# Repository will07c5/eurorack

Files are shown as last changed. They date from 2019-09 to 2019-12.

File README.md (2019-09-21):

This an attempt to build various basic analog synthesizer parts in the Eurorack form-factor. It is currently using clones of Curtis Electromusic ICs. Why, you might ask? Mostly just for fun and education.

The circuits are mostly based on the datasheets and various circuits around the web. In particular the triangle to sine conversion in the VCO uses part of Ray Wilson's VCO circuit.

Build at your own risk!

Note that these are currently only partially tested and working.

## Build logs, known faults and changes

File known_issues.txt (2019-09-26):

================ AS3340_VCO =================

================ AS3310_ADSR ================

================ AS3360_VCA =================

================ AS3320_VCF =================

================ ER_Bus_Board ===============

- "Upside down" (power input is on the left rather than the right)
- Missing descriptions of ports on the silk screen
- Need more metal around mounting holes

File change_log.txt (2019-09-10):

================ AS3340_VCO ================

Rev. 1:

- Initial design using SMD ICs.

Rev. 2:

- Added text indicating type of board and rev
- Switched to socketed DIP chips for easier repair
- Changed tuning method to 4 pot (as described in the AS3340 tuning doc)
- Adjusted various resistor values.
- Switched to precision input resistors

================ AS3320_VCF ================

Rev. 1:

- Initial design

================ AS3360_VCA ================

Rev. 1:

- Initial design

================ AS3310_ADSR ===============

Rev. 1:

- Initial design

================ ER_Bus_Board ==============

Rev. 1:

- Initial design

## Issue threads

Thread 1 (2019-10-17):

ADSR: LED incorrectly connected.

will07c5, 2019-10-17:
LED should be at minimum brightness when the envelope generator outputs 0V and max brightness at 5V output.

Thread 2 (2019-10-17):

ADSR: Resistors under AS3310

will07c5, 2019-10-17:
When the AS3310 got switched to the other side of the board the resistors didn't get moved so they overlap with the IC.

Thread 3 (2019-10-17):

VCF: Mounting hole misaligned

will07c5, 2019-10-17:
One of the mounting holes between the Main board and IO board is misaligned.

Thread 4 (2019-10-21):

VCO: PWM CV voltage summer circuit is wrong

will07c5, 2019-10-21:
There's a missing resistor between the first and second op amp.

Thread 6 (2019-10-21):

ADSR: Sustain resistor values are wrong

will07c5, 2019-10-21:
Sustain input differs from attack, decay and release. Needs to divide form 12V to 5V rather than 12V to 224mV.

Closed 2019-12-01.

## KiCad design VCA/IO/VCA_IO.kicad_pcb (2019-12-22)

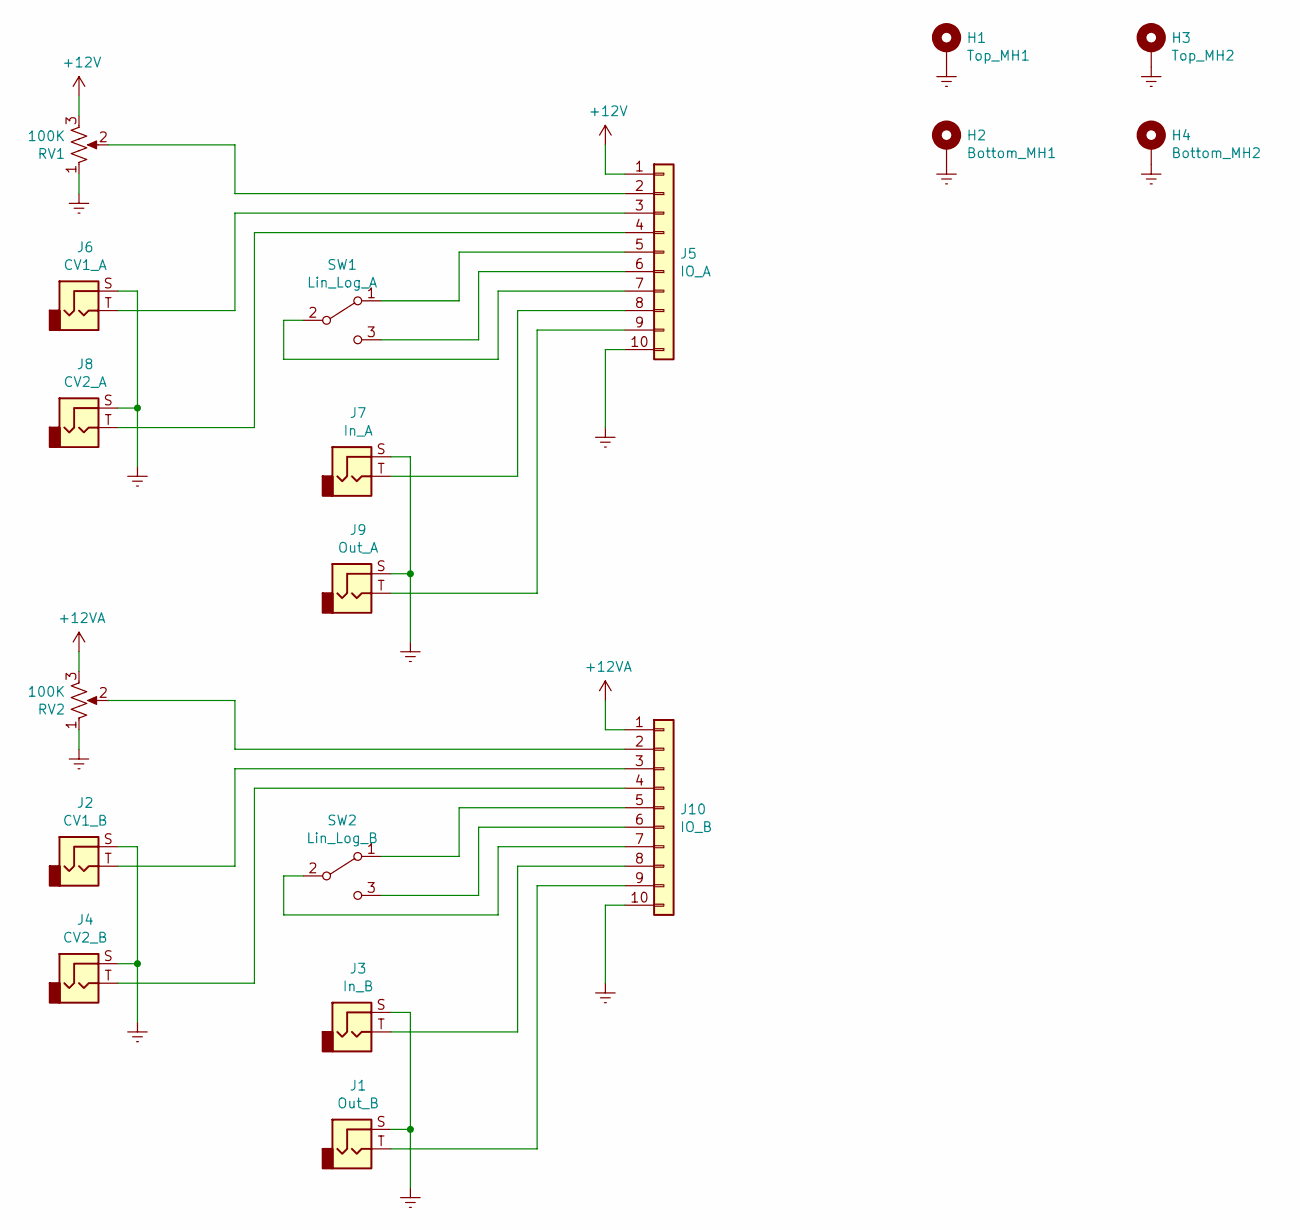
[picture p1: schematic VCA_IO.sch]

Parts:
H1: Top_MH1; eurorack_mounting_hole
H2: Bottom_MH1; eurorack_mounting_hole
H3: Top_MH2; eurorack_mounting_hole
H4: Bottom_MH2; eurorack_mounting_hole
J1: Out_B; Jack_3.5mm_QingPu_WQP-PJ398SM_Vertical_CircularHoles
J2: CV1_B; Jack_3.5mm_QingPu_WQP-PJ398SM_Vertical_CircularHoles
J3: In_B; Jack_3.5mm_QingPu_WQP-PJ398SM_Vertical_CircularHoles
J4: CV2_B; Jack_3.5mm_QingPu_WQP-PJ398SM_Vertical_CircularHoles
J5: IO_A; PinSocket_1x10_P2.54mm_Vertical
J6: CV1_A; Jack_3.5mm_QingPu_WQP-PJ398SM_Vertical_CircularHoles
J7: In_A; Jack_3.5mm_QingPu_WQP-PJ398SM_Vertical_CircularHoles
J8: CV2_A; Jack_3.5mm_QingPu_WQP-PJ398SM_Vertical_CircularHoles
J9: Out_A; Jack_3.5mm_QingPu_WQP-PJ398SM_Vertical_CircularHoles
J10: IO_B; PinSocket_1x10_P2.54mm_Vertical
RV1, RV2: 100K; Potentiometer_TT_P0915N
SW1: Lin_Log_A; switch
SW2: Lin_Log_B; switch

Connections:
+12V: J5.1, RV1.3
+12VA: J10.1, RV2.3
GNDREF: H1.1, H2.1, H3.1, H4.1, J1.S, J2.S, J3.S, J4.S, J5.10, J6.S, J7.S, J8.S, J9.S, J10.10, RV1.1, RV2.1
unnamed: J1.T, J10.9
unnamed: J5.2, RV1.2
unnamed: J5.3, J6.T
unnamed: J5.4, J8.T
unnamed: J5.5, SW1.1 (A)
unnamed: J5.6, SW1.3 (C)
unnamed: J5.7, SW1.2 (B)
unnamed: J5.8, J7.T
unnamed: J5.9, J9.T
unnamed: J10.2, RV2.2
unnamed: J2.T, J10.3
unnamed: J4.T, J10.4
unnamed: J10.5, SW2.1 (A)
unnamed: J10.6, SW2.3 (C)
unnamed: J10.7, SW2.2 (B)
unnamed: J3.T, J10.8

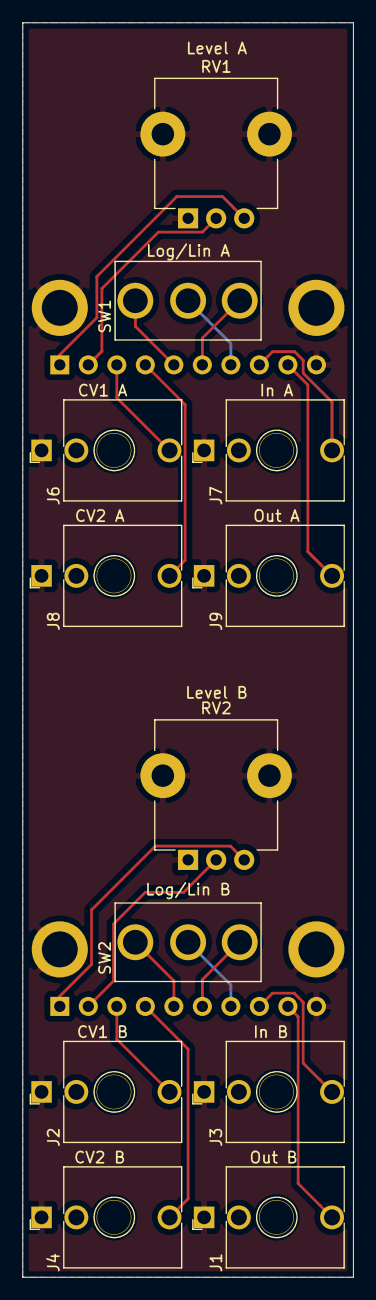
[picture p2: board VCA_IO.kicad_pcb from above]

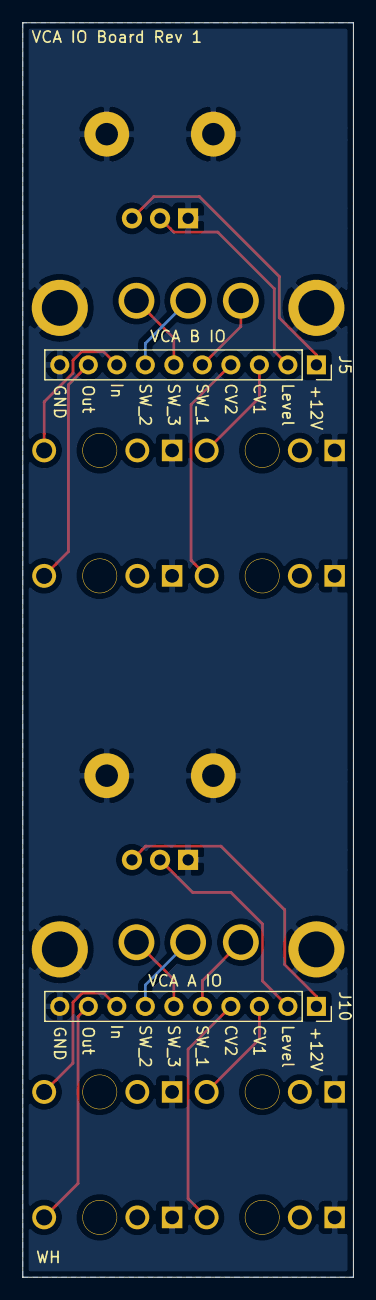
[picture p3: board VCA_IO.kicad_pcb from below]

Board: 2 copper layers, 29.5 x 111.8 mm, 18 parts (2 on the bottom side), 19 nets.

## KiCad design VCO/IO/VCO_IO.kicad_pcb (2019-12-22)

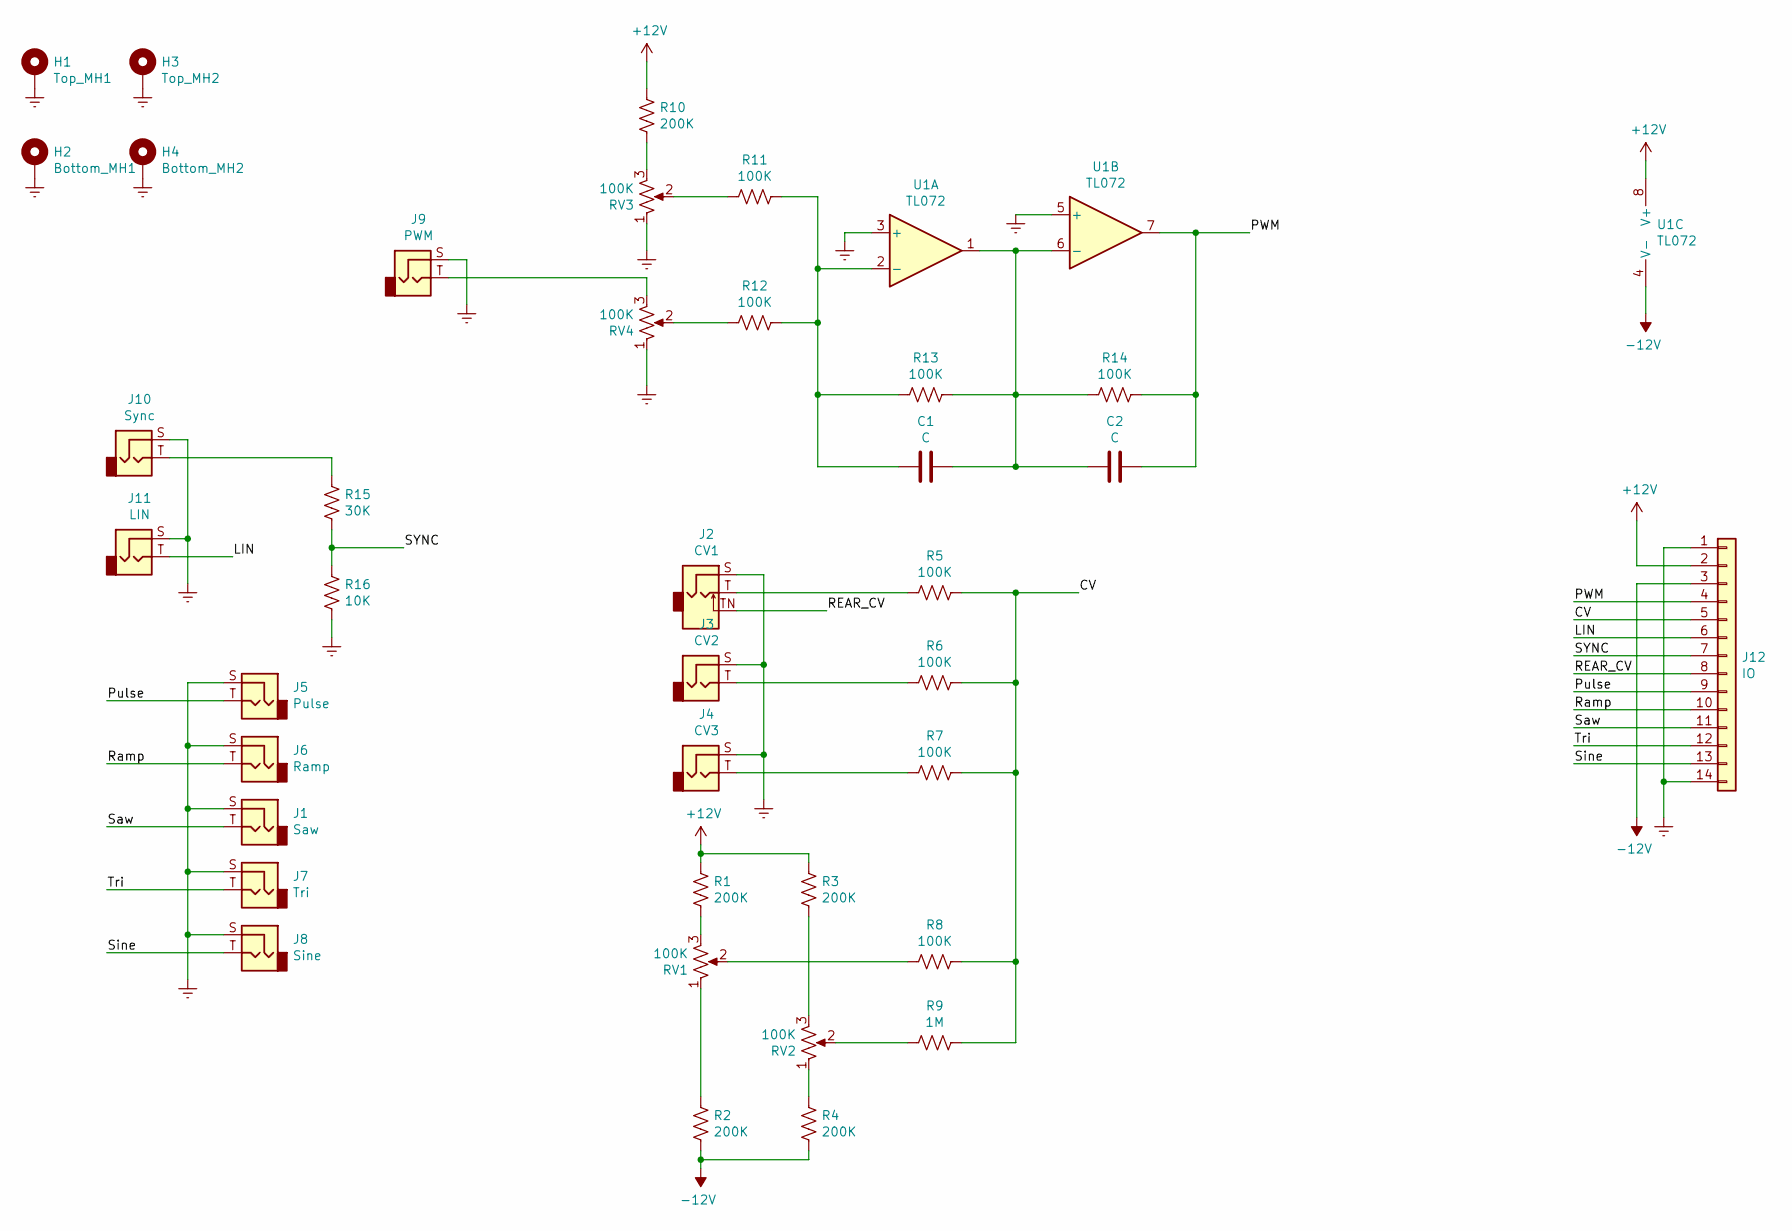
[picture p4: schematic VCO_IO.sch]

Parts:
C1, C2: C; C_0805_2012Metric
H1: Top_MH1; eurorack_mounting_hole
H2: Bottom_MH1; eurorack_mounting_hole
H3: Top_MH2; eurorack_mounting_hole
H4: Bottom_MH2; eurorack_mounting_hole
J1: Saw; Jack_3.5mm_QingPu_WQP-PJ398SM_Vertical_CircularHoles
J2: CV1; Jack_3.5mm_QingPu_WQP-PJ398SM_Vertical_CircularHoles
J3: CV2; Jack_3.5mm_QingPu_WQP-PJ398SM_Vertical_CircularHoles
J4: CV3; Jack_3.5mm_QingPu_WQP-PJ398SM_Vertical_CircularHoles
J5: Pulse; Jack_3.5mm_QingPu_WQP-PJ398SM_Vertical_CircularHoles
J6: Ramp; Jack_3.5mm_QingPu_WQP-PJ398SM_Vertical_CircularHoles
J7: Tri; Jack_3.5mm_QingPu_WQP-PJ398SM_Vertical_CircularHoles
J8: Sine; Jack_3.5mm_QingPu_WQP-PJ398SM_Vertical_CircularHoles
J9: PWM; Jack_3.5mm_QingPu_WQP-PJ398SM_Vertical_CircularHoles
J10: Sync; Jack_3.5mm_QingPu_WQP-PJ398SM_Vertical_CircularHoles
J11: LIN; Jack_3.5mm_QingPu_WQP-PJ398SM_Vertical_CircularHoles
J12: IO; PinSocket_1x14_P2.54mm_Vertical
R1, R2, R3, R4, R10: 200K; R_0805_2012Metric
R5, R6, R7, R8, R11, R12, R13, R14: 100K; R_0805_2012Metric
R9: 1M; R_0805_2012Metric
R15: 30K; R_0805_2012Metric
R16: 10K; R_0805_2012Metric
RV1, RV2, RV3, RV4: 100K; Potentiometer_TT_P0915N
U1: TL072; DIP-8_W7.62mm

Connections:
+12V: J12.2, R1.1, R3.1, R10.1, U1.8 (V+)
-12V: J12.3, R2.2, R4.2, U1.4 (V-)
/CV: J12.5, R5.1, R6.1, R7.1, R8.1, R9.1
/LIN: J11.T, J12.6
/PWM: C2.1, J12.4, R14.1, U1.7
/Pulse: J5.T, J12.9
/REAR_CV: J2.TN, J12.8
/Ramp: J6.T, J12.10
/SYNC: J12.7, R15.2, R16.1
/Saw: J1.T, J12.11
/Sine: J8.T, J12.13
/Tri: J7.T, J12.12
GNDREF: H1.1, H2.1, H3.1, H4.1, J1.S, J2.S, J3.S, J4.S, J5.S, J6.S, J7.S, J8.S, J9.S, J10.S, J11.S, J12.1, J12.14, R16.2, RV3.1, RV4.1, U1.3 (+), U1.5 (+)
unnamed: C1.1, C2.2, R13.1, R14.2, U1.1, U1.6 (-)
unnamed: C1.2, R11.1, R12.1, R13.2, U1.2 (-)
unnamed: J2.T, R5.2
unnamed: J3.T, R6.2
unnamed: J4.T, R7.2
unnamed: J9.T, RV4.3
unnamed: J10.T, R15.1
unnamed: R1.2, RV1.3
unnamed: R2.1, RV1.1
unnamed: R3.2, RV2.3
unnamed: R4.1, RV2.1
unnamed: R8.2, RV1.2
unnamed: R9.2, RV2.2
unnamed: R10.2, RV3.3
unnamed: R11.2, RV3.2
unnamed: R12.2, RV4.2

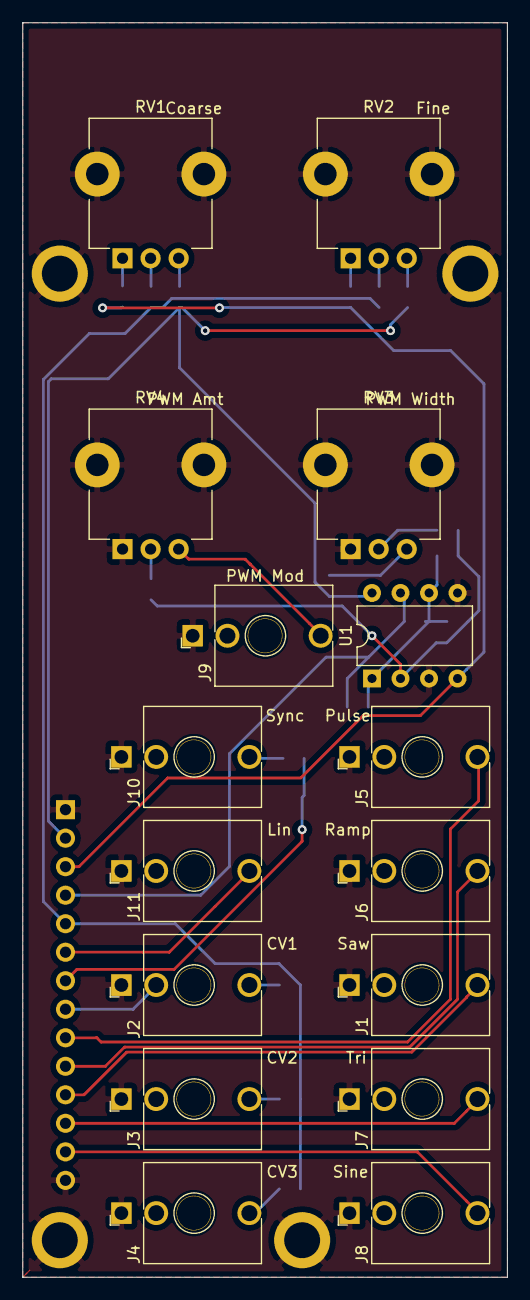
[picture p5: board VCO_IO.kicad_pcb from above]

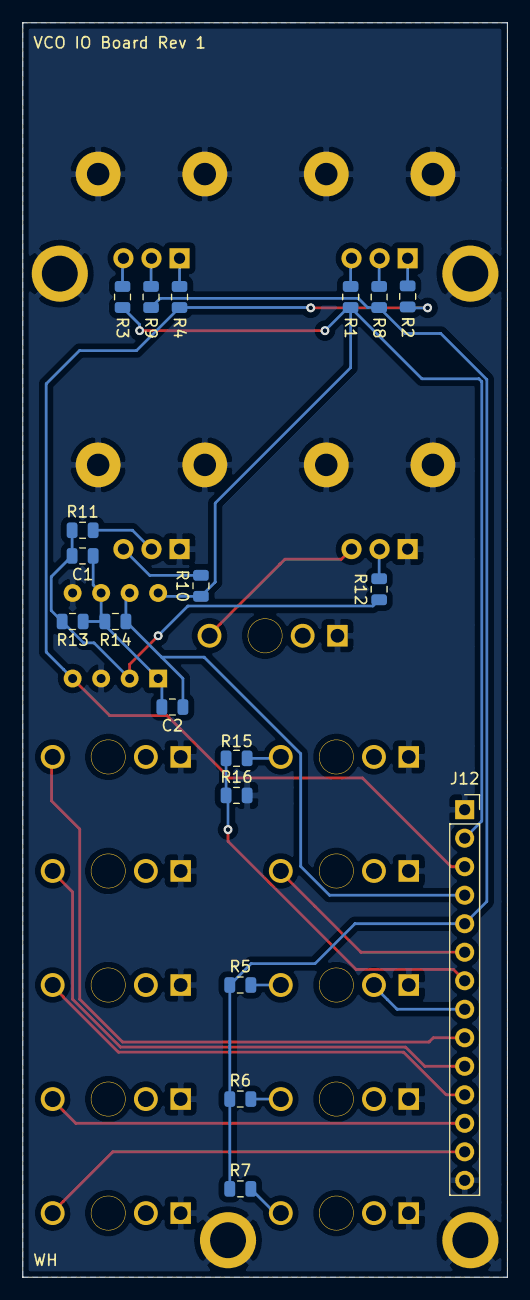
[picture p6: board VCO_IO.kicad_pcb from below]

Board: 2 copper layers, 43.2 x 111.8 mm, 39 parts (19 on the bottom side), 29 nets.

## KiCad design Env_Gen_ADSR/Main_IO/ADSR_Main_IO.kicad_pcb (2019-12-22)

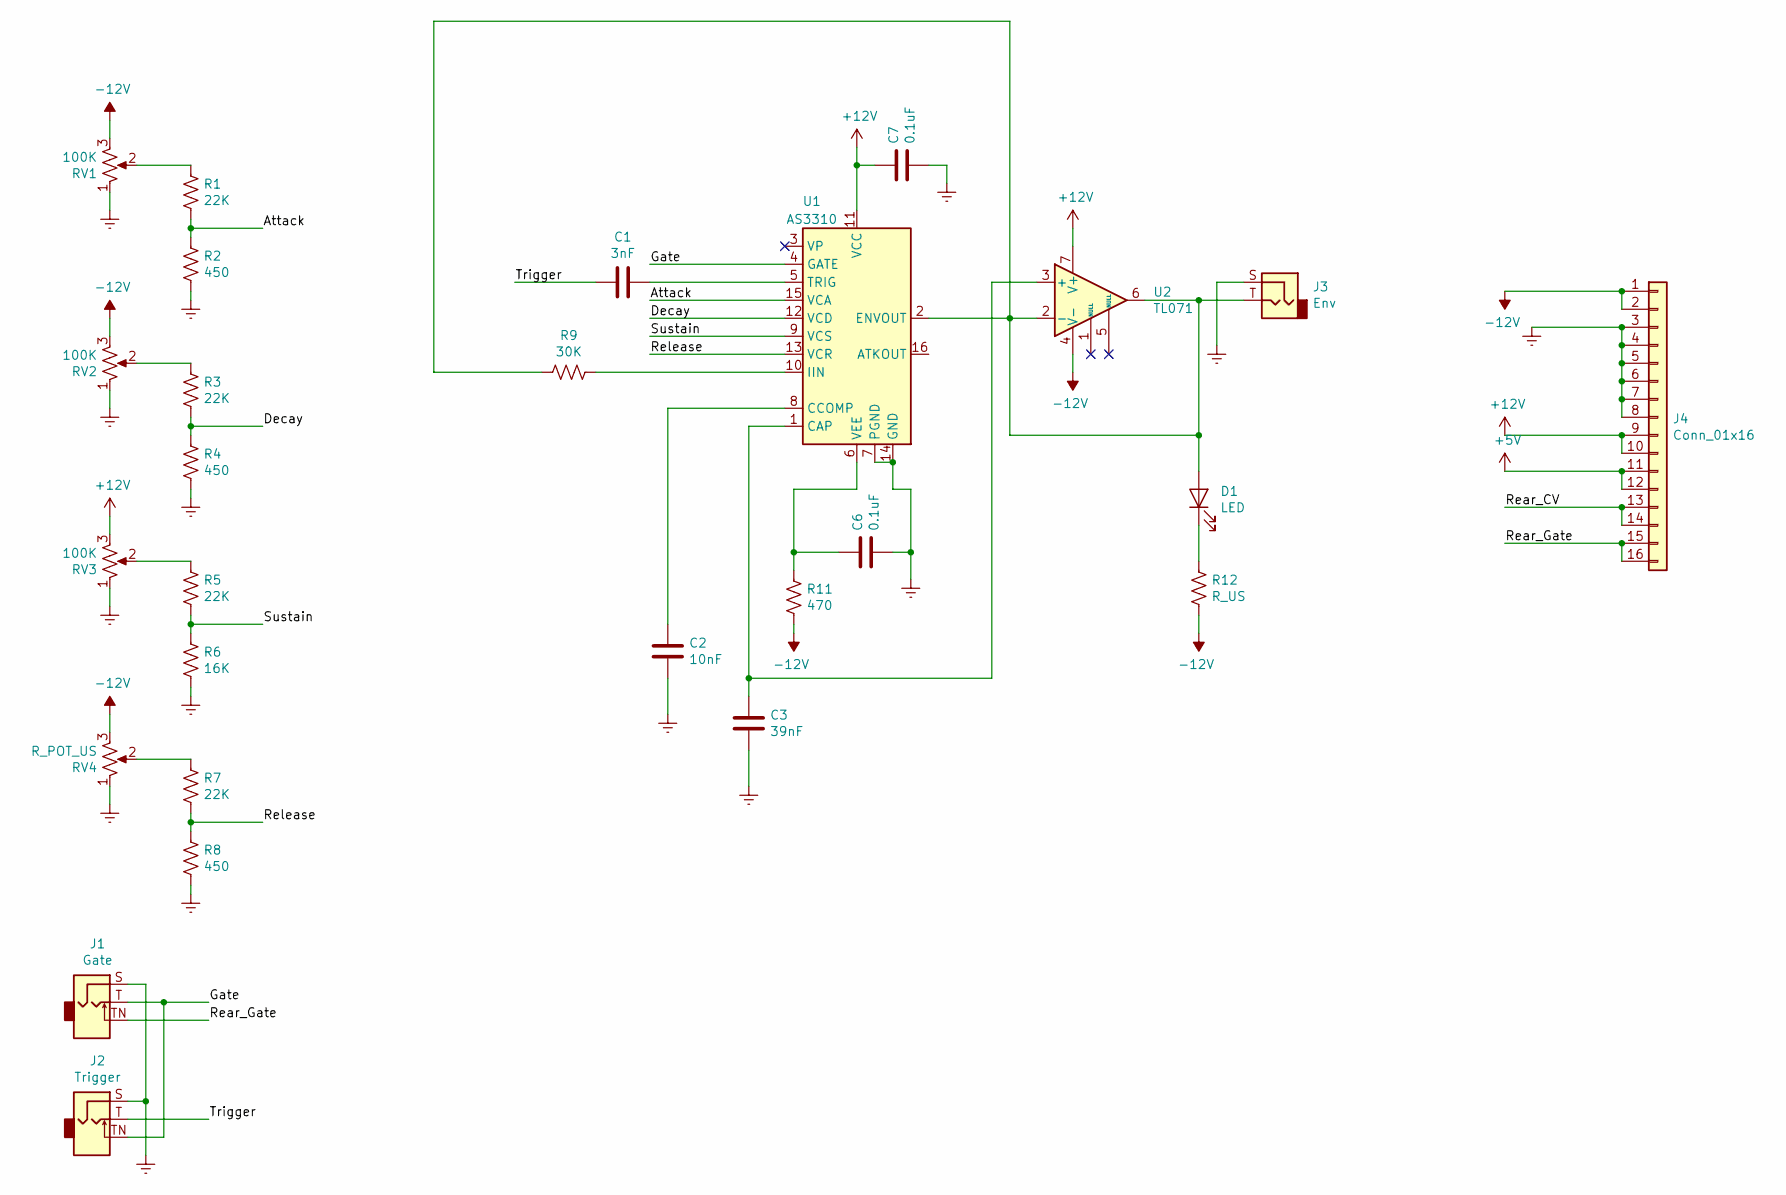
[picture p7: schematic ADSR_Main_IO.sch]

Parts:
C1: 3nF; C_0805_2012Metric
C2: 10nF; C_0805_2012Metric
C3: 39nF; C_0805_2012Metric
C6, C7: 0.1uF; C_0805_2012Metric
D1: LED; LED_D5.0mm
J1: Gate; Jack_3.5mm_QingPu_WQP-PJ398SM_Vertical_CircularHoles
J2: Trigger; Jack_3.5mm_QingPu_WQP-PJ398SM_Vertical_CircularHoles
J3: Env; Jack_3.5mm_QingPu_WQP-PJ398SM_Vertical_CircularHoles
J4: Conn_01x16; IDC-Header_2x08_P2.54mm_Vertical
R1, R3, R5, R7: 22K; R_0805_2012Metric
R2, R4, R8: 450; R_0805_2012Metric
R6: 16K; R_0805_2012Metric
R9: 30K; R_0805_2012Metric
R11: 470; R_0805_2012Metric
R12: R_US; R_0805_2012Metric
RV1, RV2, RV3: 100K; Potentiometer_TT_P0915N
RV4: R_POT_US; Potentiometer_TT_P0915N
U1: AS3310; DIP-16_W7.62mm
U2: TL071; DIP-8_W7.62mm

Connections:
+5V: J4.11, J4.12
+12V: C7.1, J4.9, J4.10, RV3.3, U1.11 (VCC), U2.7 (V+)
-12V: J4.1, J4.2, R11.2, R12.2, RV1.3, RV2.3, RV4.3, U2.4 (V-)
/Attack: R1.2, R2.1, U1.15 (VCA)
/Decay: R3.2, R4.1, U1.12 (VCD)
/Gate: J1.T, J2.TN, U1.4 (GATE)
/Rear_CV: J4.13, J4.14
/Rear_Gate: J1.TN, J4.15, J4.16
/Release: R7.2, R8.1, U1.13 (VCR)
/Sustain: R5.2, R6.1, U1.9 (VCS)
/Trigger: C1.2, J2.T
GNDREF: C2.2, C3.2, C6.2, C7.2, J1.S, J2.S, J3.S, J4.3, J4.4, J4.5, J4.6, J4.7, J4.8, R2.2, R4.2, R6.2, R8.2, RV1.1, RV2.1, RV3.1, RV4.1, U1.7 (PGND), U1.14 (GND)
unnamed: C1.1, U1.5 (TRIG)
unnamed: C2.1, U1.8 (CCOMP)
unnamed: C3.1, U1.1 (CAP), U2.3 (+)
unnamed: C6.1, R11.1, U1.6 (VEE)
unnamed: D1.1 (K), R12.1
unnamed: D1.2 (A), J3.T, R9.2, U1.2 (ENVOUT), U2.2 (-), U2.6
unnamed: R1.1, RV1.2
unnamed: R3.1, RV2.2
unnamed: R5.1, RV3.2
unnamed: R7.1, RV4.2
unnamed: R9.1, U1.10 (IIN)

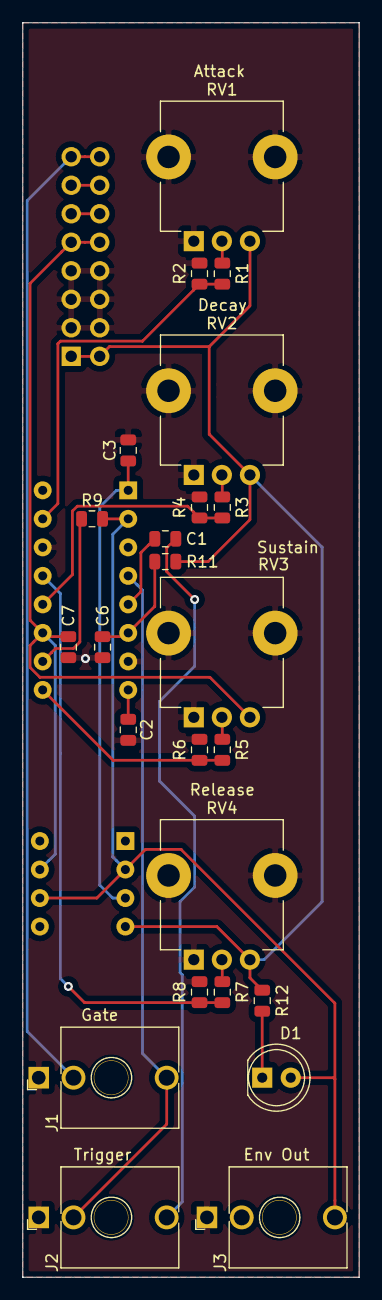
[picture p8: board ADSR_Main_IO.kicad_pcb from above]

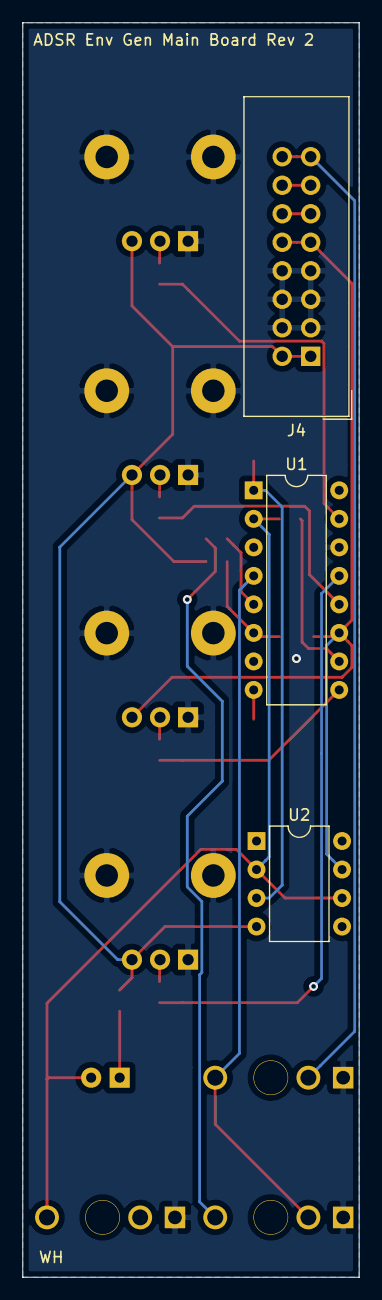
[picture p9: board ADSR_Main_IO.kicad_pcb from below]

Board: 2 copper layers, 30.0 x 111.8 mm, 27 parts (3 on the bottom side), 23 nets.

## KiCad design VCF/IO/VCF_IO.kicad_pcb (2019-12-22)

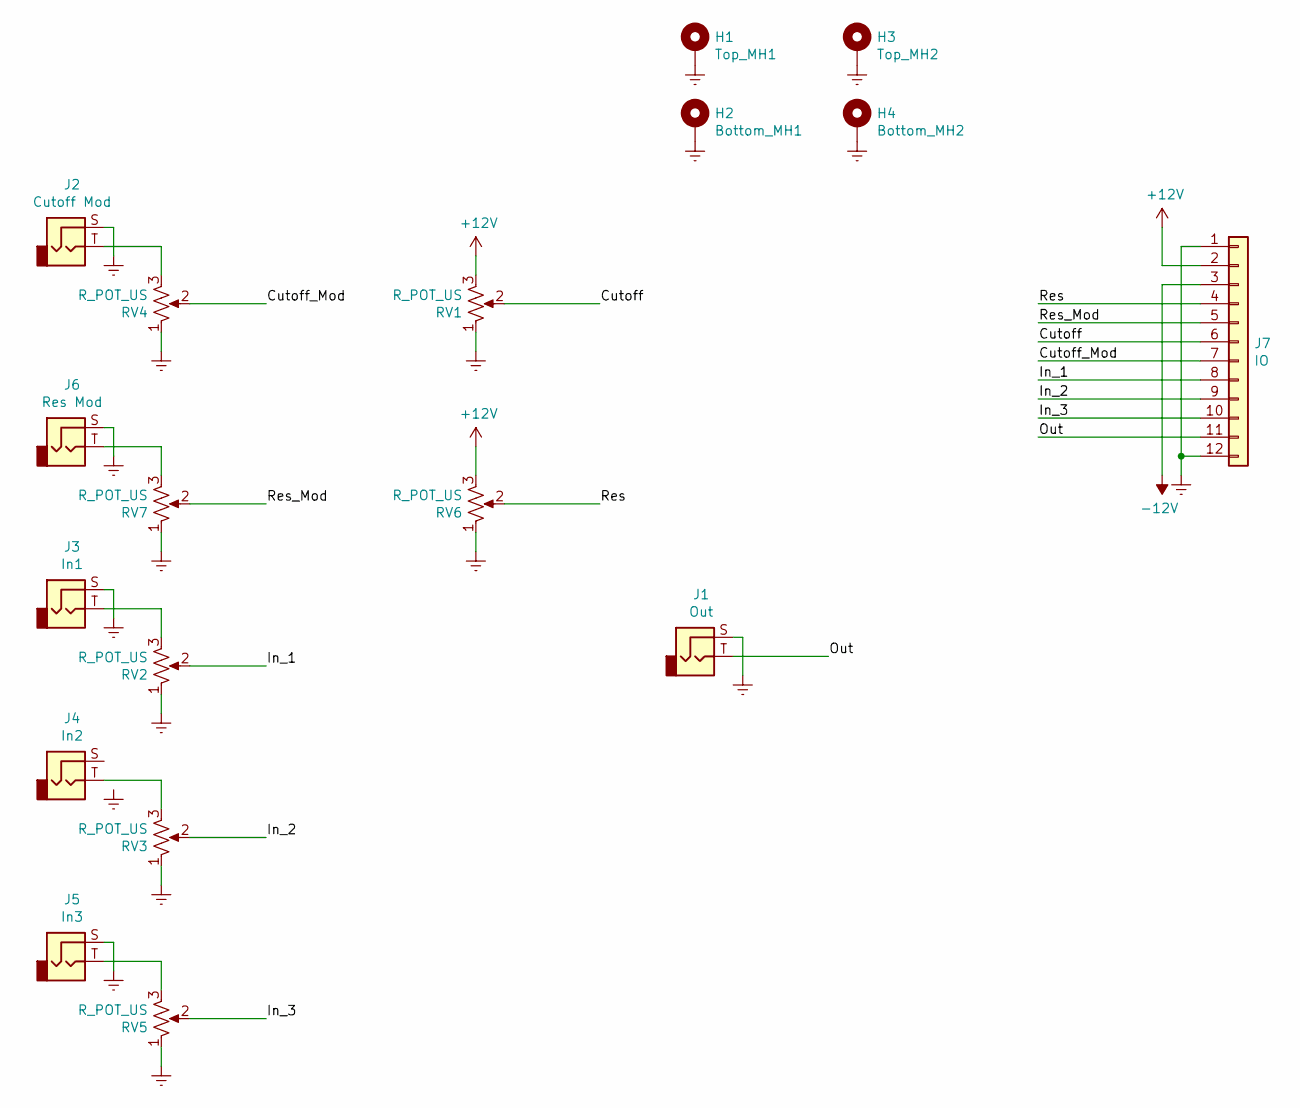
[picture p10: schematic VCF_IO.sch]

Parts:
H1: Top_MH1; eurorack_mounting_hole
H2: Bottom_MH1; eurorack_mounting_hole
H3: Top_MH2; eurorack_mounting_hole
H4: Bottom_MH2; eurorack_mounting_hole
J1: Out; Jack_3.5mm_QingPu_WQP-PJ398SM_Vertical_CircularHoles
J2: Cutoff Mod; Jack_3.5mm_QingPu_WQP-PJ398SM_Vertical_CircularHoles
J3: In1; Jack_3.5mm_QingPu_WQP-PJ398SM_Vertical_CircularHoles
J4: In2; Jack_3.5mm_QingPu_WQP-PJ398SM_Vertical_CircularHoles
J5: In3; Jack_3.5mm_QingPu_WQP-PJ398SM_Vertical_CircularHoles
J6: Res Mod; Jack_3.5mm_QingPu_WQP-PJ398SM_Vertical_CircularHoles
J7: IO; PinSocket_1x12_P2.54mm_Vertical
RV1, RV2, RV3, RV4, RV5, RV6, RV7: R_POT_US; Potentiometer_TT_P0915N

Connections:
+12V: J7.2, RV1.3, RV6.3
-12V: J7.3
/Cutoff: J7.6, RV1.2
/Cutoff_Mod: J7.7, RV4.2
/In_1: J7.8, RV2.2
/In_2: J7.9, RV3.2
/In_3: J7.10, RV5.2
/Out: J1.T, J7.11
/Res: J7.4, RV6.2
/Res_Mod: J7.5, RV7.2
GNDREF: H1.1, H2.1, H3.1, H4.1, J1.S, J2.S, J3.S, J5.S, J6.S, J7.1, J7.12, RV1.1, RV2.1, RV3.1, RV4.1, RV5.1, RV6.1, RV7.1
unnamed: J2.T, RV4.3
unnamed: J3.T, RV2.3
unnamed: J4.T, RV3.3
unnamed: J5.T, RV5.3
unnamed: J6.T, RV7.3

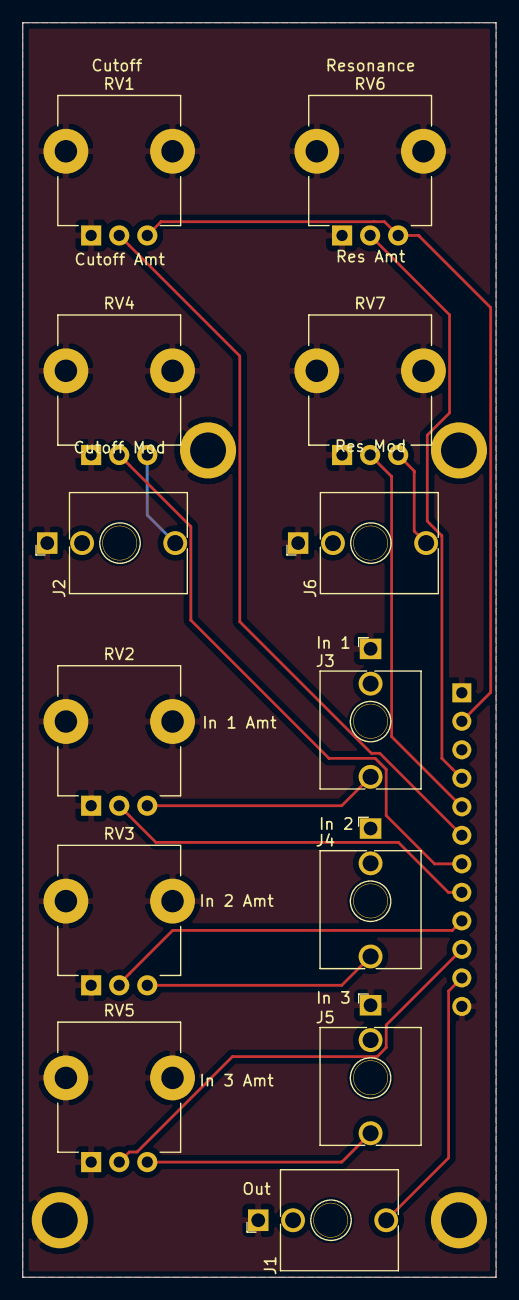
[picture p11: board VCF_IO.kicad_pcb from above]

Board: 2 copper layers, 42.2 x 111.8 mm, 18 parts (1 on the bottom side), 15 nets.

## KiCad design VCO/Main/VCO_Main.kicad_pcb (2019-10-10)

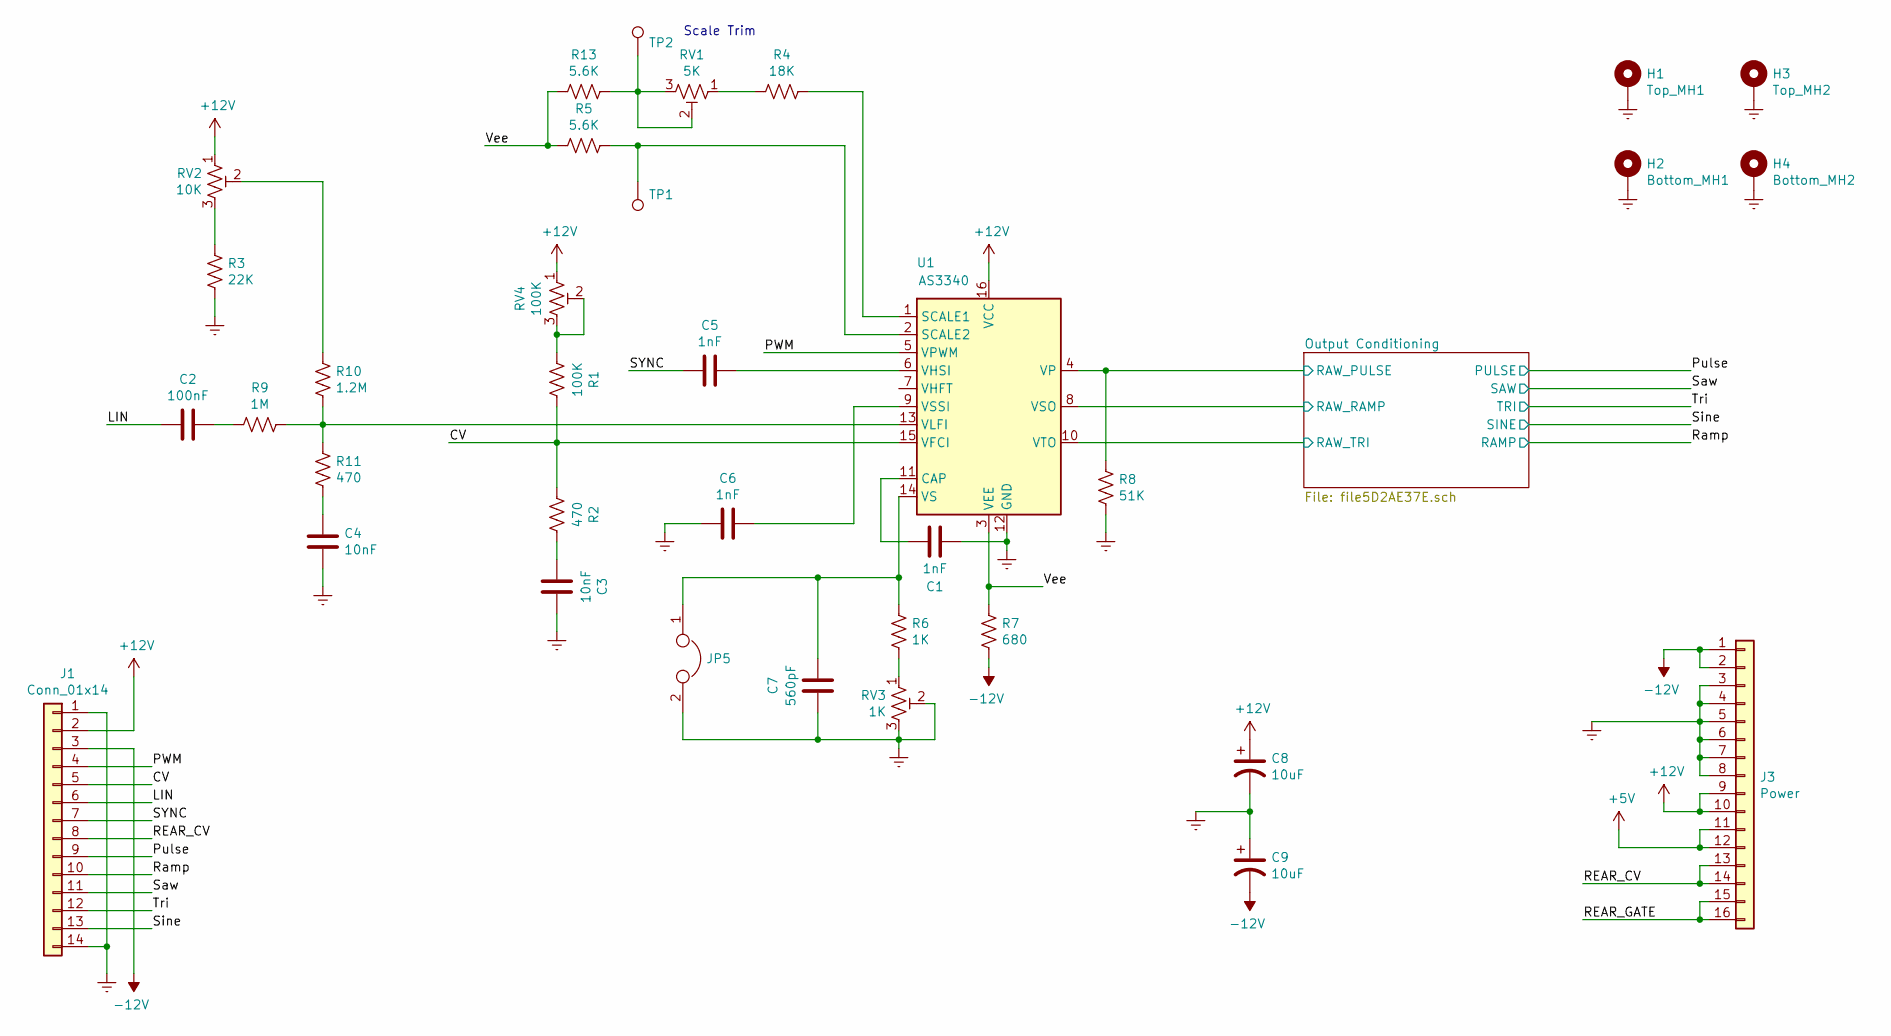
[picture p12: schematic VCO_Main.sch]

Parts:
C1: 1nF; Mica_Cap
C2: 100nF; C_0805_2012Metric
C3, C4: 10nF; C_0805_2012Metric
C5, C6: 1nF; C_0805_2012Metric
C7: 560pF; C_0805_2012Metric
C8, C9: 10uF; CP_Elec_4x3
H1: Top_MH1; eurorack_mounting_hole
H2: Bottom_MH1; eurorack_mounting_hole
H3: Top_MH2; eurorack_mounting_hole
H4: Bottom_MH2; eurorack_mounting_hole
J1: Conn_01x14; PinHeader_1x14_P2.54mm_Vertical
J3: Power; IDC-Header_2x08_P2.54mm_Vertical
JP5: Jumper; PinHeader_1x02_P2.54mm_Vertical
R1: 100K; R_0805_2012Metric
R2, R11: 470; R_0805_2012Metric
R3: 22K; R_0805_2012Metric
R4: 18K; R_0805_2012Metric
R5, R13: 5.6K; R_0805_2012Metric
R6: 1K; R_0805_2012Metric
R7: 680; R_0805_2012Metric
R8: 51K; R_0805_2012Metric
R9: 1M; R_0805_2012Metric
R10: 1.2M; R_0805_2012Metric
RV1: 5K; Potentiometer_Bourns_3296W_Vertical
RV2: 10K; Potentiometer_Bourns_3296W_Vertical
RV3: 1K; Potentiometer_Bourns_3296W_Vertical
RV4: 100K; Potentiometer_Bourns_3296W_Vertical
TP1, TP2: TestPoint; TestPoint_Pad_D2.0mm
U1: AS3340; DIP-16_W7.62mm

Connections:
+5V: J3.11, J3.12
+12V: C8.1, J1.2, J3.9, J3.10, RV2.1, RV4.1, U1.16 (VCC); also elsewhere on the board
-12V: C9.2, J1.3, J3.1, J3.2, R7.2; also elsewhere on the board
/CV: J1.5, R1.1, R2.2, U1.15 (VFCI)
/LIN: C2.2, J1.6
/Output Conditioning/RAW_PULSE: R8.2, U1.4 (VP); also elsewhere on the board
/Output Conditioning/RAW_RAMP: U1.8 (VSO); also elsewhere on the board
/Output Conditioning/RAW_TRI: U1.10 (VTO); also elsewhere on the board
/PWM: J1.4, U1.5 (VPWM)
/Pulse: J1.9; also elsewhere on the board
/REAR_CV: J1.8, J3.13, J3.14
/REAR_GATE: J3.15, J3.16
/Ramp: J1.10; also elsewhere on the board
/SYNC: C5.2, J1.7
/Saw: J1.11; also elsewhere on the board
/Sine: J1.13; also elsewhere on the board
/Tri: J1.12; also elsewhere on the board
/Vee: R5.1, R7.1, R13.1, U1.3 (VEE)
GNDREF: C1.1, C3.1, C4.1, C6.2, C7.1, C8.2, C9.1, H1.1, H2.1, H3.1, H4.1, J1.1, J1.14, J3.3, J3.4, J3.5, J3.6, J3.7, J3.8, JP5.2, R3.1, R8.1, RV3.2, RV3.3, U1.12 (GND); also elsewhere on the board
unnamed: C1.2, U1.11 (CAP)
unnamed: C2.1, R9.2
unnamed: C3.2, R2.1
unnamed: C4.2, R11.1
unnamed: C5.1, U1.6 (VHSI)
unnamed: C6.1, U1.9 (VSSI)
unnamed: C7.2, JP5.1, R6.2, U1.14 (VS)
unnamed: R1.2, RV4.2, RV4.3
unnamed: R3.2, RV2.3
unnamed: R4.1, RV1.1
unnamed: R4.2, U1.1 (SCALE1)
unnamed: R5.2, TP1.1, U1.2 (SCALE2)
unnamed: R6.1, RV3.1
unnamed: R9.1, R10.1, R11.2, U1.13 (VLFI)
unnamed: R10.2, RV2.2
unnamed: R13.2, RV1.2, RV1.3, TP2.1

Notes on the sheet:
Scale Trim


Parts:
C10, C11, C12, C13: C; C_0805_2012Metric
C14, C15, C16, C17, C18, C19: 0.1uF; C_0805_2012Metric
R12, R14, R24, R35, R36, R39: 10K; R_0805_2012Metric
R23, R29, R34, R37: 100K; R_0805_2012Metric
R25, R27: 20K; R_0805_2012Metric
R26: 470K; R_0805_2012Metric
R28, R33: 1K; R_0805_2012Metric
R30: 130K; R_0805_2012Metric
R31: 1M; R_0805_2012Metric
R32: 4.7K; R_0805_2012Metric
R38: 12K; R_0805_2012Metric
RV6, RV10, RV11: 20K; Potentiometer_Bourns_3296W_Vertical
RV7, RV8: 100K; Potentiometer_Bourns_3296W_Vertical
RV9: 1M; Potentiometer_Bourns_3296W_Vertical
U5: LM13700; DIP-16_W7.62mm
U6, U7: TL072; DIP-8_W7.62mm

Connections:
+12V: C14.2, C16.2, C18.2, R23.1, R31.1, R34.1, R37.1, RV8.1, RV9.3, U5.11 (V+), U6.8 (V+), U7.8 (V+); also elsewhere on the board
-12V: C15.2, C17.2, C19.2, R32.2, RV8.3, U5.6 (V-), U6.4 (V-), U7.4 (V-); also elsewhere on the board
/Output Conditioning/RAW_PULSE: R38.1; also elsewhere on the board
/Output Conditioning/RAW_RAMP: R35.1; also elsewhere on the board
/Output Conditioning/RAW_TRI: R24.1; also elsewhere on the board
/Pulse: C13.1, R39.2, U7.1; also elsewhere on the board
/Ramp: C12.1, R14.2, U6.7; also elsewhere on the board
/Saw: C10.1, R12.1, R36.2, U6.1; also elsewhere on the board
/Sine: R33.2; also elsewhere on the board
/Tri: C11.1, R25.2, RV7.1, U7.7; also elsewhere on the board
GNDREF: C14.1, C15.1, C16.1, C17.1, C18.1, C19.1, R28.2, R30.2, RV6.3, RV10.3, RV11.3, U5.3 (+), U5.13 (-), U5.14 (+), U6.5 (+); also elsewhere on the board
unnamed: C10.2, R35.2, R36.1, U6.2 (-)
unnamed: C11.2, R24.2, R25.1, U7.6 (-)
unnamed: C12.2, R12.2, R14.1, U6.6 (-)
unnamed: C13.2, R38.2, R39.1, U7.2 (-)
unnamed: R23.2, RV6.1
unnamed: R26.1, RV8.2
unnamed: R26.2, R27.1, R28.1, U5.4 (-)
unnamed: R27.2, RV7.2, RV7.3
unnamed: R29.1, U5.1
unnamed: R29.2, RV9.1, RV9.2
unnamed: R30.1, R31.2, U5.5, U5.7
unnamed: R32.1, R33.1, U5.8
unnamed: R34.2, RV10.1
unnamed: R37.2, RV11.1
unnamed: RV6.2, U7.5 (+)
unnamed: RV10.2, U6.3 (+)
unnamed: RV11.2, U7.3 (+)

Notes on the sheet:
Tri Offset Trim
Sine Bias Trim
Sine Shape Trim
Sine Level Trim
Saw Offset Trim
Pulse Offset Trim

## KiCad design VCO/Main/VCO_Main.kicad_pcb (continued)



Board: 2 copper layers, 43.2 x 92.7 mm, 73 parts (19 on the bottom side), 52 nets.

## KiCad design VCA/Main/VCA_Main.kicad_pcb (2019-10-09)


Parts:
C1, C2: CP1; CP_Elec_4x3
C3: 5nF; C_0805_2012Metric
C4, C5, C10, C11, C12, C13, C14, C15: 0.1uF; C_0805_2012Metric
C6, C7, C8, C9: C; C_0805_2012Metric
H1: Top_MH1; eurorack_mounting_hole
H2: Bottom_MH1; eurorack_mounting_hole
H3: Top_MH2; eurorack_mounting_hole
H4: Bottom_MH2; eurorack_mounting_hole
J1: Power; IDC-Header_2x05_P2.54mm_Vertical
J5: IO_A; PinHeader_1x10_P2.54mm_Vertical
J10: IO_B; PinHeader_1x10_P2.54mm_Vertical
R1, R2, R3, R4, R5, R6, R8, R9, R10, R11, R12, R13, R15: 100K; R_0805_2012Metric
R7: 240K; R_0805_2012Metric
R14, R16: 18K; R_0805_2012Metric
R17, R20: 16K; R_0805_2012Metric
R18, R19: 2.4K; R_0805_2012Metric
R21, R22, R23, R24: 47K; R_0805_2012Metric
U1: AS3360; DIP-14_W7.62mm
U2, U3, U4: TL072; DIP-8_W7.62mm

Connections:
+12V: C1.1, C4.2, C10.2, C12.2, C15.2, J1.9, J1.10, J5.1, J10.1, U1.14 (VCC), U2.8 (V+), U3.8 (V+), U4.8 (V+)
-12V: C2.2, C5.2, C11.2, C13.2, C14.2, J1.1, J1.2, U1.7 (VEE), U2.4 (V-), U3.4 (V-), U4.4 (V-)
/CV1_A: J5.3, R2.2
/CV1_B: J10.3, R5.2
/CV2_A: J5.4, R3.2
/CV2_B: J10.4, R6.2
/In_A: J5.8, R21.1
/In_B: J10.8, R22.1
/Level_A: J5.2, R1.2
/Level_B: J10.2, R4.2
/Out_A: J5.9, U4.6 (-), U4.7
/Out_B: J10.9, U4.1, U4.2 (-)
/SW_Com_A: J5.7, U1.12 (VE2)
/SW_Com_B: J10.7, U1.3 (VE1)
/SW_Lin_A: J5.5, U1.11 (VO2)
/SW_Lin_B: J10.5, U1.4 (VO1)
/SW_Log_A: J5.6, R17.2, R18.1
/SW_Log_B: J10.6, R19.2, R20.1
GNDREF: C1.2, C2.1, C3.2, C4.1, C5.1, C10.1, C11.1, C12.1, C13.1, C14.1, C15.1, H1.1, H2.1, H3.1, H4.1, J1.3, J1.4, J1.5, J1.6, J1.7, J1.8, J5.10, J10.10, R14.2, R16.2, R23.2, R24.2, U1.1 (GND), U2.3 (+), U2.5 (+), U3.3 (+), U3.5 (+)
unnamed: C3.1, R18.2, R19.1, U1.8 (VREF)
unnamed: C6.1, R7.1, R9.2, U2.1
unnamed: C6.2, R1.1, R2.1, R3.1, R7.2, U2.2 (-)
unnamed: C7.1, R8.1, R10.2, U3.1
unnamed: C7.2, R4.1, R5.1, R6.1, R8.2, U3.2 (-)
unnamed: C8.1, R11.1, R13.1, U2.7
unnamed: C8.2, R9.1, R11.2, U2.6 (-)
unnamed: C9.1, R12.1, R15.1, U3.7
unnamed: C9.2, R10.1, R12.2, U3.6 (-)
unnamed: R13.2, R14.1, R17.1, U1.10 (VC2)
unnamed: R15.2, R16.1, R20.2, U1.5 (VC1)
unnamed: R21.2, U1.9 (II2)
unnamed: R22.2, U1.6 (II1)
unnamed: R23.1, U1.13 (IO2), U4.5 (+)
unnamed: R24.1, U1.2 (IO1), U4.3 (+)



Board: 2 copper layers, 29.5 x 68.3 mm, 50 parts (5 on the bottom side), 34 nets.

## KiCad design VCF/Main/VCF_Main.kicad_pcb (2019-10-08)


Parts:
C1: 15uF; CP_Elec_4x3
C2, C3, C4, C5: 300pF; Mica_Cap
C6: 1uF; CP_Elec_4x3
C7: 33pF; C_0805_2012Metric
C8, C9: 10uF; CP_Elec_4x3
C10, C11, C12, C13: C; C_0805_2012Metric
C14, C15, C16, C17, C18, C19, C20, C21: 0.1uF; C_0805_2012Metric
H1: Top_MH1; eurorack_mounting_hole
H2: Bottom_MH1; eurorack_mounting_hole
H3: Top_MH2; eurorack_mounting_hole
H4: Bottom_MH2; eurorack_mounting_hole
J1: Power; PinHeader_1x12_P2.54mm_Vertical
J2: Power; IDC-Header_2x05_P2.54mm_Vertical
R1, R2, R3, R4, R12, R18, R21, R27, R31, R32: 100K; R_0805_2012Metric
R5, R6, R7, R9, R10, R14, R19, R22: 82K; R_0805_2012Metric
R8, R13, R20: 220K; R_0805_2012Metric
R11: 300K; R_0805_2012Metric
R15: 125K; R_0805_2012Metric
R16: 150K; R_0805_2012Metric
R17, R29: 200K; R_0805_2012Metric
R23: 44.2K; R_0805_2012Metric
R24: 39K; R_0805_2012Metric
R25: 47K; R_0805_2012Metric
R26: TC; Tempco
R28: 750; R_0805_2012Metric
R30: 1K; R_0805_2012Metric
RV6: 25K; Potentiometer_Bourns_3296W_Vertical
RV7: 1K; Potentiometer_Bourns_3296W_Vertical
U1, U2, U4: TL072; DIP-8_W7.62mm
U3: AS3320; DIP-18_W7.62mm

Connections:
+12V: C8.1, C15.2, C16.2, C18.2, C20.2, J1.2, J2.9, J2.10, U1.8 (V+), U2.8 (V+), U3.14 (VCC), U4.8 (V+)
-12V: C9.2, C17.2, C19.2, C21.2, J1.3, J2.1, J2.2, R8.1, R13.1, R16.2, R20.1, RV7.3, U1.4 (V-), U2.4 (V-), U4.4 (V-)
/Cutoff: J1.6, R15.2
/Cutoff_Mod: J1.7, R17.2
/In_1: J1.8, R1.2
/In_2: J1.9, R2.2
/In_3: J1.10, R3.2
/Out: J1.11, R30.1
/Res: J1.4, R11.2
/Res_Mod: J1.5, R12.2
GNDREF: C2.2, C3.2, C4.2, C5.2, C8.2, C9.1, C14.1, C15.1, C16.1, C17.1, C18.1, C19.1, C20.1, C21.1, H1.1, H2.1, H3.1, H4.1, J1.1, J1.12, J2.3, J2.4, J2.5, J2.6, J2.7, J2.8, R26.2, U1.3 (+), U1.5 (+), U2.3 (+), U2.5 (+), U3.3 (GND), U4.3 (+), U4.5 (+)
unnamed: C1.1, R5.2
unnamed: C1.2, C10.2, R4.1, U1.7
unnamed: C2.1, U3.5
unnamed: C3.1, U3.4
unnamed: C4.1, U3.16
unnamed: C5.1, U3.11
unnamed: C6.1, R22.1, U3.10
unnamed: C6.2, R25.2, R27.2
unnamed: C7.1, R27.1, R29.2, U1.2 (-)
unnamed: C7.2, R29.1, R30.2, U1.1
unnamed: C10.1, R1.1, R2.1, R3.1, R4.2, U1.6 (-)
unnamed: C11.1, R11.1, R12.1, R18.2, U2.2 (-)
unnamed: C11.2, R18.1, R32.2, U2.1
unnamed: C12.1, R15.1, R16.1, R17.1, R21.2, U4.6 (-)
unnamed: C12.2, R21.1, R23.2, U4.7
unnamed: C13.1, R31.2, R32.1, U2.6 (-)
unnamed: C13.2, R24.2, R31.1, U2.7
unnamed: C14.2, R28.1, U3.13 (VEE)
unnamed: R5.1, R6.2, U3.1
unnamed: R6.1, R7.2, U3.7
unnamed: R7.1, R8.2, R9.2, U3.2
unnamed: R10.1, R13.2, R14.2, U3.17
unnamed: R9.1, R10.2, U3.6
unnamed: R14.1, R19.2, U3.15
unnamed: R19.1, R20.2, R22.2, U3.18
unnamed: R23.1, RV6.2, RV6.3
unnamed: R24.1, U3.9 (IRES)
unnamed: R25.1, U3.8 (VRES)
unnamed: R26.1, RV6.1, U3.12 (VCFI)
unnamed: R28.2, RV7.1, RV7.2
unnamed: U4.1, U4.2 (-)



Board: 2 copper layers, 39.6 x 75.2 mm, 65 parts (14 on the bottom side), 42 nets.

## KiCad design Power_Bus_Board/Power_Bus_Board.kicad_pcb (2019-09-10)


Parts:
D1, D2, D3: LED; LED_D5.0mm
J1: Bus_8; IDC-Header_2x08_P2.54mm_Vertical
J2: Power_Out; TerminalBlock_bornier-4_P5.08mm
J3: CV_Gate_Out_2; PinHeader_1x03_P2.54mm_Vertical
J4: Bus_7; IDC-Header_2x08_P2.54mm_Vertical
J5: Bus_6; IDC-Header_2x08_P2.54mm_Vertical
J6: Bus_5; IDC-Header_2x08_P2.54mm_Vertical
J7: Bus_4; IDC-Header_2x08_P2.54mm_Vertical
J8: Bus_3; IDC-Header_2x08_P2.54mm_Vertical
J9: Bus_2; IDC-Header_2x08_P2.54mm_Vertical
J10: Bus_1; IDC-Header_2x08_P2.54mm_Vertical
J11: Power_In; TerminalBlock_bornier-4_P5.08mm
J12: CV_Gate_Out_1; TerminalBlock_bornier-3_P5.08mm
J13: CV_Gate_In_2; PinHeader_1x03_P2.54mm_Vertical
J14: CV_Gate_In_1; TerminalBlock_bornier-3_P5.08mm
R1, R2, R3: R_US; R_0805_2012Metric

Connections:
+5V: J1.11, J1.12, J2.1, J4.11, J4.12, J5.11, J5.12, J6.11, J6.12, J7.11, J7.12, J8.11, J8.12, J9.11, J9.12, J10.11, J10.12, J11.4, R3.1
+12V: J1.9, J1.10, J2.2, J4.9, J4.10, J5.9, J5.10, J6.9, J6.10, J7.9, J7.10, J8.9, J8.10, J9.9, J9.10, J10.9, J10.10, J11.3, R1.1
-12V: D2.1 (K), J1.1, J1.2, J2.4, J4.1, J4.2, J5.1, J5.2, J6.1, J6.2, J7.1, J7.2, J8.1, J8.2, J9.1, J9.2, J10.1, J10.2, J11.1
/CV: J1.13, J1.14, J3.2, J4.13, J4.14, J5.13, J5.14, J6.13, J6.14, J7.13, J7.14, J8.13, J8.14, J9.13, J9.14, J10.13, J10.14, J12.2, J13.2, J14.2
/Gate: J1.15, J1.16, J3.3, J4.15, J4.16, J5.15, J5.16, J6.15, J6.16, J7.15, J7.16, J8.15, J8.16, J9.15, J9.16, J10.15, J10.16, J12.3, J13.3, J14.3
GNDREF: D1.1 (K), D3.1 (K), J1.3, J1.4, J1.5, J1.6, J1.7, J1.8, J2.3, J3.1, J4.3, J4.4, J4.5, J4.6, J4.7, J4.8, J5.3, J5.4, J5.5, J5.6, J5.7, J5.8, J6.3, J6.4, J6.5, J6.6, J6.7, J6.8, J7.3, J7.4, J7.5, J7.6, J7.7, J7.8, J8.3, J8.4, J8.5, J8.6, J8.7, J8.8, J9.3, J9.4, J9.5, J9.6, J9.7, J9.8, J10.3, J10.4, J10.5, J10.6, J10.7, J10.8, J11.2, J12.1, J13.1, J14.1, R2.1
unnamed: D1.2 (A), R1.2
unnamed: D2.2 (A), R2.2
unnamed: D3.2 (A), R3.2


Board: 2 copper layers, 189.2 x 33.0 mm, 20 parts (0 on the bottom side), 9 nets.

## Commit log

2019-09-10 AS3340_VCO rev1 (with SMD ICs)
    [AS3340_VCO-B_Cu.gbr, AS3340_VCO-B_Mask.gbr, AS3340_VCO-B_Paste.gbr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]
2019-09-10 AS3340_VCO rev 2 AS3310_ADSR rev 1 AS3320_VCF rev 1 AS3360_VCA rev 1 ER_Bus_Board rev 1
    [AS3310_ADSR-B_Cu.gbr, AS3310_ADSR-B_Mask.gbr, AS3310_ADSR-B_Paste.gbr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]
2019-09-13 Add front panel and IO boards for VCO
    [AS3340_VCO_FP.kicad_pcb, AS3340_VCO_FP.sch, AS3340_VCO_IO.kicad_pcb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]
2019-09-13 Re-do VCO board to support new front panel board
    [AS3340_VCO.kicad_pcb, AS3340_VCO.sch, file5D2AE37E.sch]
2019-09-14 Adding front panel for ADSR
    [AS3310_ADSR_FP.kicad_pcb, AS3340_VCO_FP.sch]
2019-09-14 Combine IO and main ADSR boards
    [AS3310_ADSR-B_Cu.gbr, AS3310_ADSR-B_Mask.gbr, AS3310_ADSR-B_Paste.gbr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]
2019-09-20 Adding front panel board for VCA
    [AS3360_VCA_FP.kicad_pcb, AS3360_VCA_FP.sch]
2019-09-20 Organize boards in a more sane way.
    [ADSR_Front_Panel.kicad_pcb, ADSR_Front_Panel.sch, ADSR_Main_IO.kicad_pcb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]
2019-09-21 Add VCA IO board
    [VCA_Front_Panel.sch, VCA_IO.kicad_pcb, VCA_IO.sch]
2019-09-21 Update front panel to match IO board
    [VCA_Front_Panel.kicad_pcb]
2019-09-21 Re-doing VCA board to be compatible with new front panel design.
    [VCA_Main.kicad_pcb, VCA_Main.sch]
2019-09-24 Adding front panel board for VCF
    [VCF_Front_Panel.kicad_pcb, VCF_Front_Panel.sch]
2019-09-25 Move footprints to common folder and update known issues
2019-09-25 Add IO board for VCF
    [VCF_IO.kicad_pcb, VCF_IO.sch]
2019-09-25 Update VCF main board for new front panel
    [AS3320_VCF.kicad_pcb, VCF_Main.kicad_pcb, VCF_Main.sch]
2019-09-25 Add mounting holes for main board
    [VCF_IO.kicad_pcb]
2019-09-25 Fix envelope generator front panel size and alignment with IO board.
    [ADSR_Front_Panel.kicad_pcb, ADSR_Main_IO.kicad_pcb, ADSR_Main_IO.sch]
2019-09-26 Clean up VCA boards
    [VCA_Front_Panel.kicad_pcb, VCA_IO.kicad_pcb, VCA_Main.kicad_pcb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]
2019-09-26 Clean up envelope generator boards
    [ADSR_Front_Panel.kicad_pcb, ADSR_Main_IO.kicad_pcb]
2019-09-26 Clean up VCF boards
    [VCF_Front_Panel.kicad_pcb, VCF_IO.kicad_pcb, VCF_Main.kicad_pcb]
2019-09-26 Resolve most of the issues in known_issues.txt
    [AS3360_VCA-B_Cu.gbr, AS3360_VCA-B_Mask.gbr, AS3360_VCA-B_Paste.gbr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]
2019-09-26 Fix minor issues with VCO board
    [VCO_Front_Panel.kicad_pcb, VCO_IO.kicad_pcb, VCO_Main.kicad_pcb]
2019-09-26 Fix inverted resonance control input
    [VCF_IO.kicad_pcb, VCF_IO.sch, VCF_Main.kicad_pcb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]
2019-10-03 Bunch of bug fixes and tweaks
    [ADSR_Front_Panel.kicad_pcb, ADSR_Front_Panel.sch, ADSR_Main_IO.kicad_pcb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]
2019-10-03 Add resistor divider for Sync input and some capacitors.
    [VCO_IO.kicad_pcb, VCO_IO.sch]
2019-10-07 Clean up layout of VCF board
    [AS3320_VCF-B_Cu.gbr, AS3320_VCF-B_Mask.gbr, AS3320_VCF-B_Paste.gbr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]
2019-10-08 Make VCF front panel bigger. Re-align IO and FP boards.
    [VCF_Front_Panel.kicad_pcb, VCF_Front_Panel.sch, VCF_IO.kicad_pcb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]
2019-10-08 Clean up layout of VCO board
    [AS3340_VCO-B_Cu.gbr, AS3340_VCO-B_Mask.gbr, AS3340_VCO-B_Paste.gbr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]
2019-10-08 Update tick marks footprint
2019-10-09 Clean up layout of VCA board
    [VCA_Front_Panel.kicad_pcb, VCA_IO.kicad_pcb, VCA_IO.sch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]
2019-10-09 Clean up envelope gen board
    [ADSR_Front_Panel.kicad_pcb, ADSR_Main_IO.kicad_pcb, ADSR_Main_IO.sch]
2019-10-10 Added Gerber files
    [ADSR_Front_Panel-B_Cu.gbr, ADSR_Front_Panel-B_Mask.gbr, ADSR_Front_Panel-B_Paste.gbr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]
2019-12-01 Fix resistor values for ADSR Sustain
    [ADSR_Main_IO.sch]
2019-12-22 Fix backwards knobs
    [ADSR_Main_IO.kicad_pcb, ADSR_Main_IO.sch, VCA_IO.kicad_pcb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]
